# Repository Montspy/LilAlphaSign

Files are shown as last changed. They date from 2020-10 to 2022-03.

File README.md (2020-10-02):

# LilAlphaSign
Little experiment at a WiFi connected RGB sign.
Background and "alert" animations can be triggered through HTTP requests.
User Manual: [here](extras/LilAlphaSign%20User%20Manual.pdf)

### Web interface

Web interface video (http://www.youtube.com/watch?v=FNkgUU_1f1U "Click to watch")

### Background animations

Web interface video (http://www.youtube.com/watch?v=0p3MXtC2Jag "Click to watch")

### "Alert" animations

Web interface video (http://www.youtube.com/watch?v=xB9izgtYmIM "Click to watch")

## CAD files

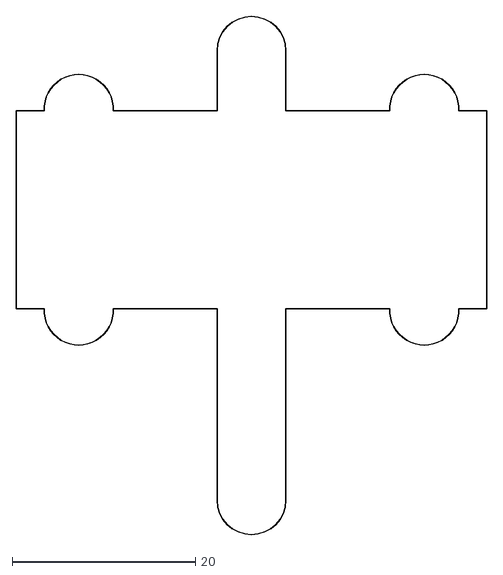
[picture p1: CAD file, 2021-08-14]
extras/cad/diffusers/dxf exports/SamW Sign - Jets acrylic diffuser.dxf
51.3 x 56.5

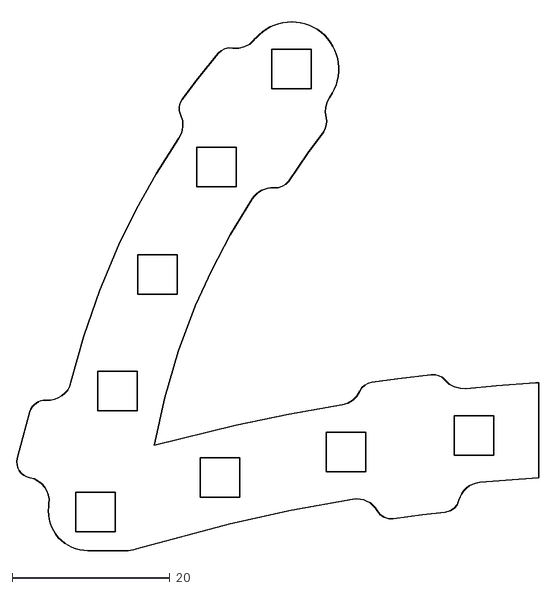
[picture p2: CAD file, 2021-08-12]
extras/cad/pcb outlines/PCB - SamW Sign - LED board 1.dxf
66.1 x 67.7

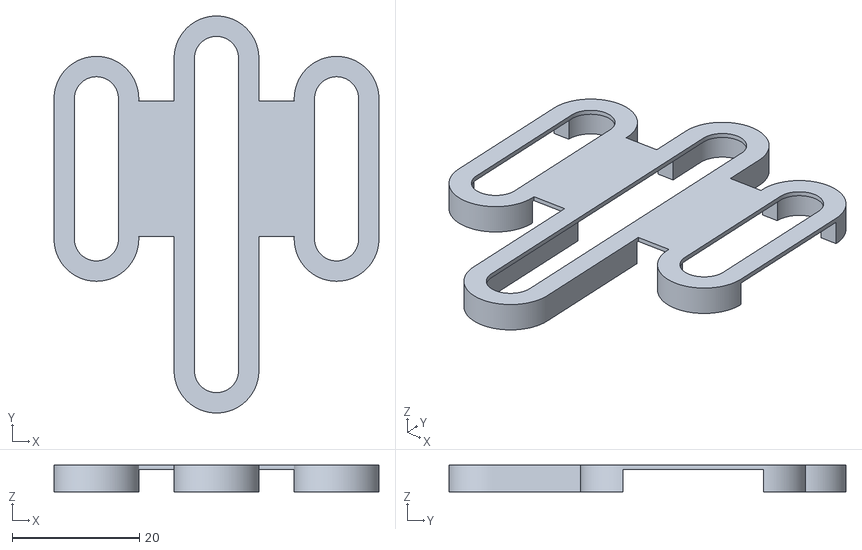
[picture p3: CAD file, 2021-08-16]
extras/cad/stl/Housing - SamW Sign - Jets cover.stl
51.0 x 62.3 x 4.17

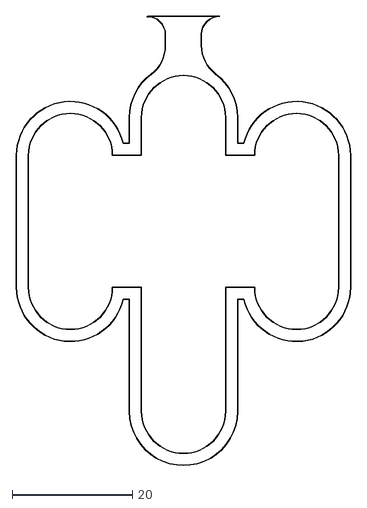
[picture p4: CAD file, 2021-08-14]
extras/cad/diffusers/dxf exports/SamW Sign - Jets.dxf
55.7 x 75.3

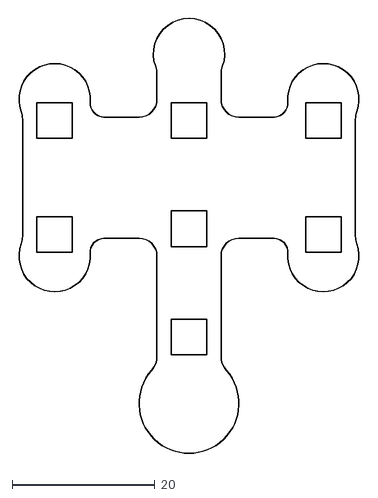
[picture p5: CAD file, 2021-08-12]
extras/cad/pcb outlines/PCB - SamW Sign - LED board jets.dxf
48.5 x 62.0

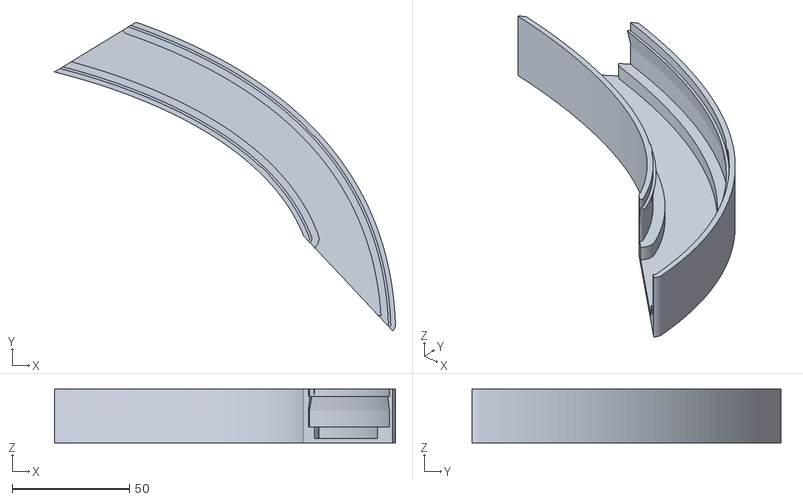
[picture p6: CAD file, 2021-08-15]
extras/cad/stl/Housing - SamW Sign - Rocket mid.stl
145.2 x 131.5 x 23.0

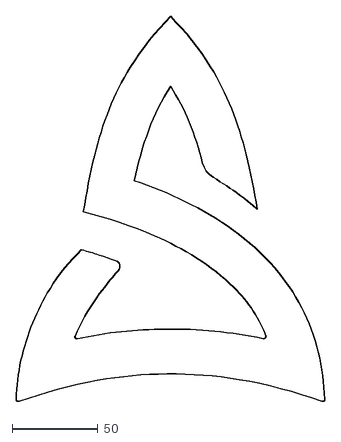
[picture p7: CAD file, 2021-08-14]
extras/cad/diffusers/dxf exports/SamW Sign - Rocket acrylic diffuser.dxf
179.7 x 224.3

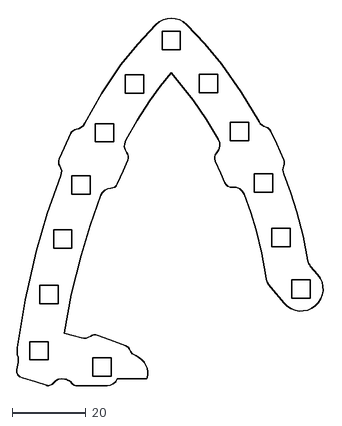
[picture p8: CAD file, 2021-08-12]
extras/cad/pcb outlines/PCB - SamW Sign - LED board 3.dxf
84.0 x 100.4

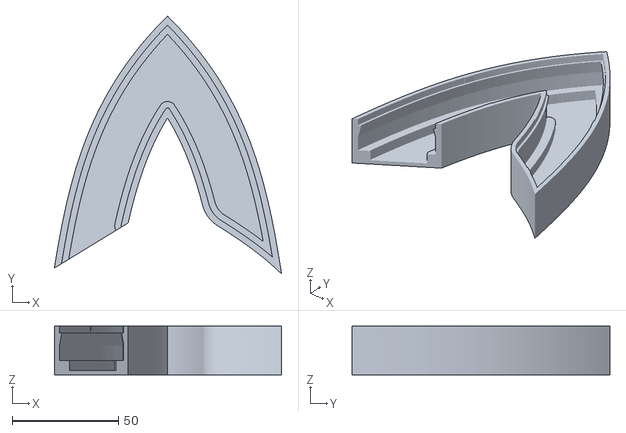
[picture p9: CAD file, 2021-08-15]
extras/cad/stl/Housing - SamW Sign - Rocket top.stl
106.9 x 121.3 x 23.0

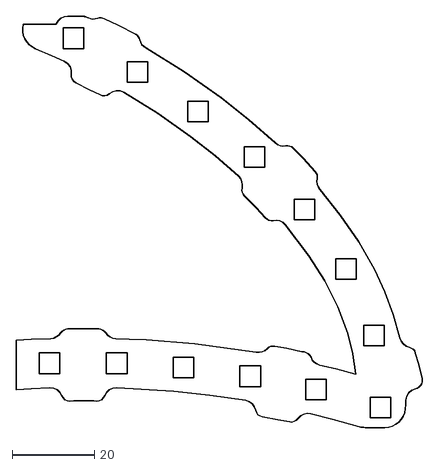
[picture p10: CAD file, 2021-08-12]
extras/cad/pcb outlines/PCB - SamW Sign - LED board 2.dxf
98.8 x 100.0

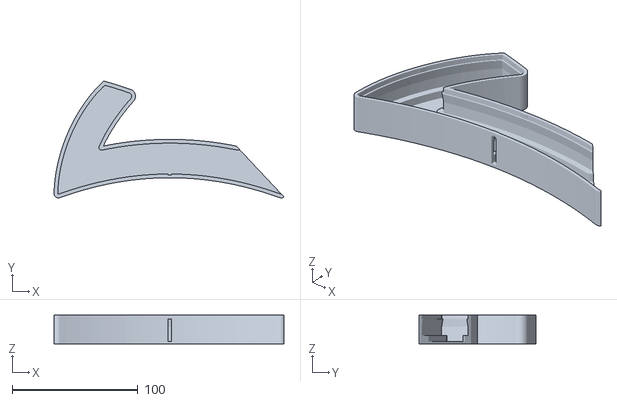
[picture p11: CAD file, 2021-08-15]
extras/cad/stl/Housing - SamW Sign - Rocket bottom.stl
182.9 x 93.0 x 23.0

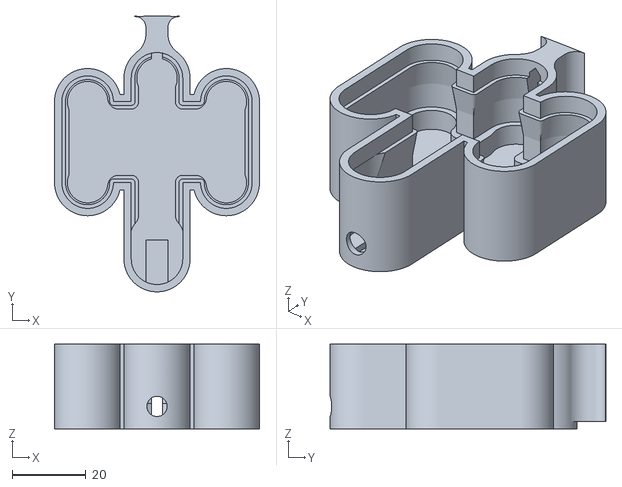
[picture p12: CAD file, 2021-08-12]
extras/cad/stl/Housing - SamW Sign - Jets.stl
55.7 x 74.9 x 23.0

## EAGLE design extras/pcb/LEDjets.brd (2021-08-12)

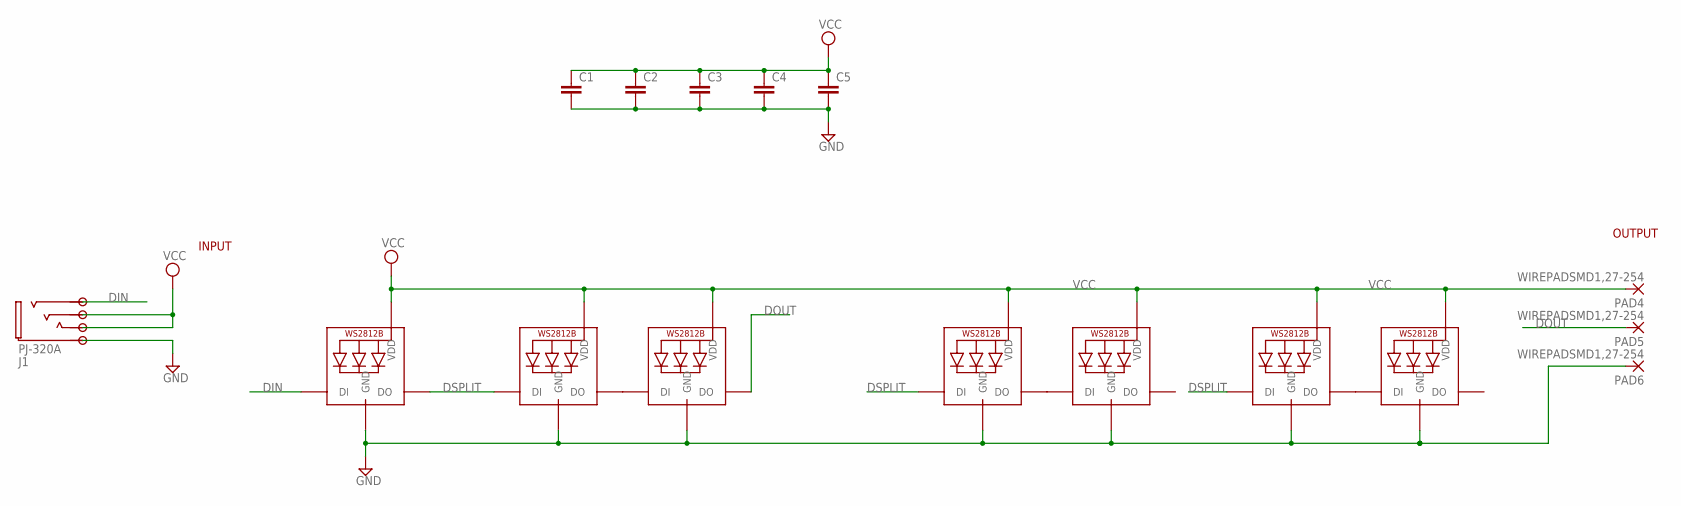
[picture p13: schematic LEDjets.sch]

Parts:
C1, C2, C3, C4, C5: C-EUC0805K; C0805K
J1: PJ-320A
LED1, LED2, LED3, LED4, LED5, LED6, LED7: WS2812B5050; WS2812B
PAD4, PAD5, PAD6: WIREPADSMD1,27-254; SMD1,27-2,54

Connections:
DIN: J1.2, LED1.4-DIN (DI)
DOUT: LED3.2-DOUT (DO), PAD5.1
DSPLIT: LED1.2-DOUT (DO), LED2.4-DIN (DI), LED4.4-DIN (DI), LED6.4-DIN (DI)
GND: C1.2, C2.2, C3.2, C4.2, C5.2, J1.5, LED1.3-GND (GND), LED2.3-GND (GND), LED3.3-GND (GND), LED4.3-GND (GND), LED5.3-GND (GND), LED6.3-GND (GND), LED7.3-GND (GND), PAD6.1
unnamed: LED2.2-DOUT (DO), LED3.4-DIN (DI)
unnamed: LED4.2-DOUT (DO), LED5.4-DIN (DI)
unnamed: LED6.2-DOUT (DO), LED7.4-DIN (DI)
VCC: C1.1, C2.1, C3.1, C4.1, C5.1, J1.3, J1.4, LED1.1-VDD (VDD), LED2.1-VDD (VDD), LED3.1-VDD (VDD), LED4.1-VDD (VDD), LED5.1-VDD (VDD), LED6.1-VDD (VDD), LED7.1-VDD (VDD), PAD4.1

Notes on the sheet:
INPUT
OUTPUT

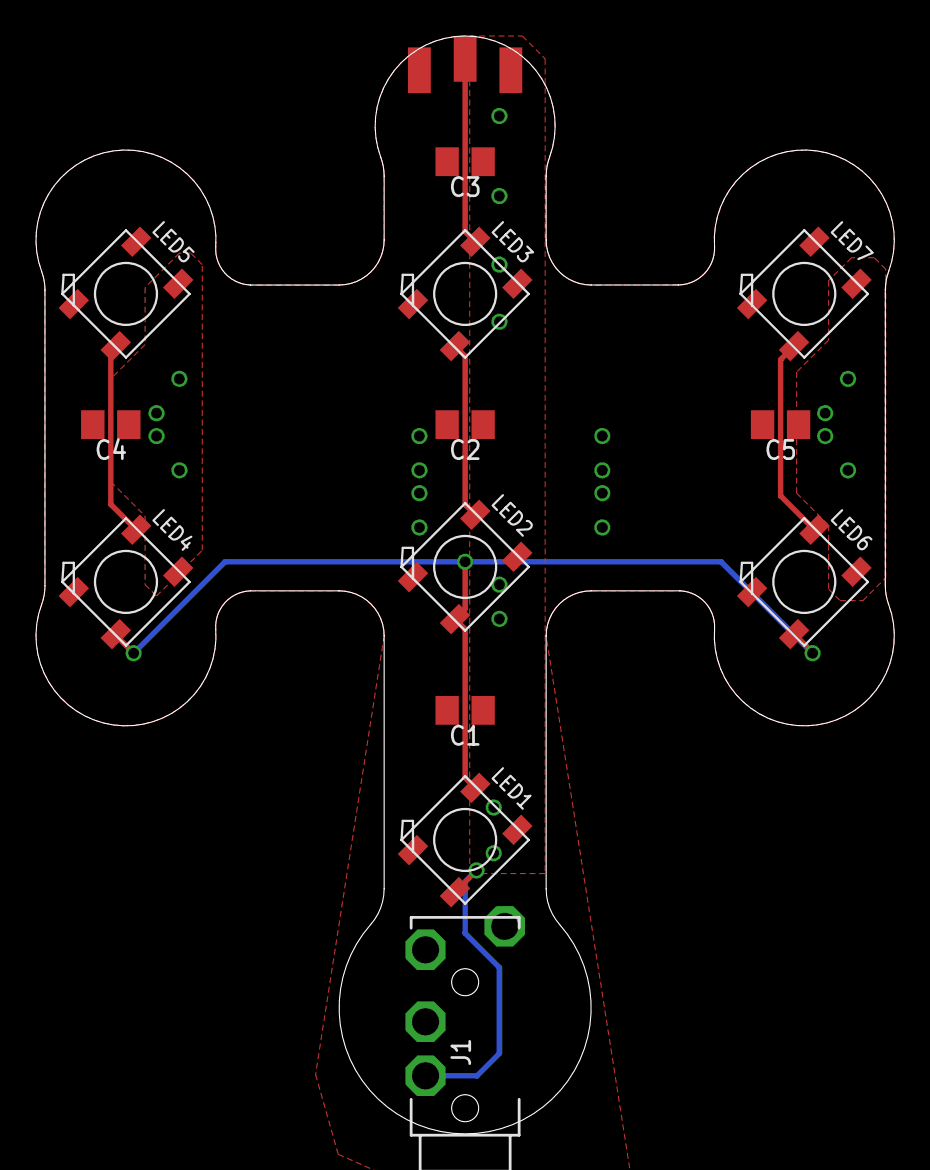
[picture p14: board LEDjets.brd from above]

Board: 2 copper layers, 47.7 x 61.0 mm, 16 parts (0 on the bottom side), 8 nets.

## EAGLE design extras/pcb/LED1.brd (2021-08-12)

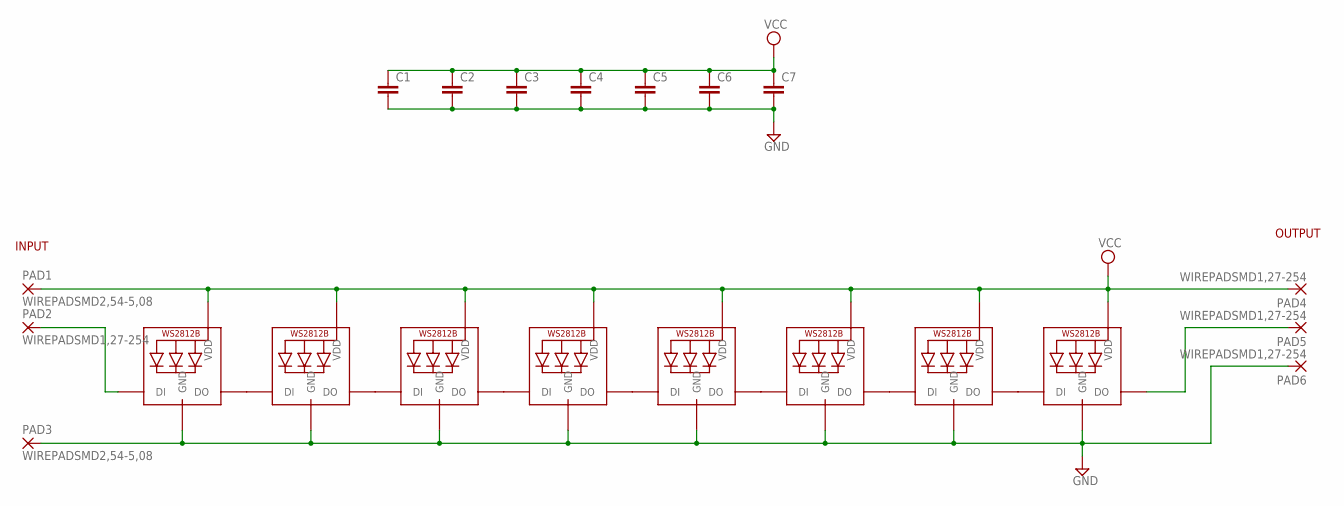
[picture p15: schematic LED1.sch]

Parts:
C1, C2, C3, C4, C5, C6, C7: C-EUC0805K; C0805K
LED1, LED2, LED3, LED4, LED5, LED6, LED7, LED8: WS2812B5050; WS2812B
PAD1, PAD3: WIREPADSMD2,54-5,08; SMD2,54-5,08
PAD2, PAD4, PAD5, PAD6: WIREPADSMD1,27-254; SMD1,27-2,54

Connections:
GND: C1.2, C2.2, C3.2, C4.2, C5.2, C6.2, C7.2, LED1.3-GND (GND), LED2.3-GND (GND), LED3.3-GND (GND), LED4.3-GND (GND), LED5.3-GND (GND), LED6.3-GND (GND), LED7.3-GND (GND), LED8.3-GND (GND), PAD3.1, PAD6.1
unnamed: LED1.2-DOUT (DO), LED2.4-DIN (DI)
unnamed: LED2.2-DOUT (DO), LED3.4-DIN (DI)
unnamed: LED3.2-DOUT (DO), LED4.4-DIN (DI)
unnamed: LED4.2-DOUT (DO), LED5.4-DIN (DI)
unnamed: LED5.2-DOUT (DO), LED6.4-DIN (DI)
unnamed: LED6.2-DOUT (DO), LED7.4-DIN (DI)
unnamed: LED1.4-DIN (DI), PAD2.1
unnamed: LED8.2-DOUT (DO), PAD5.1
unnamed: LED7.2-DOUT (DO), LED8.4-DIN (DI)
VCC: C1.1, C2.1, C3.1, C4.1, C5.1, C6.1, C7.1, LED1.1-VDD (VDD), LED2.1-VDD (VDD), LED3.1-VDD (VDD), LED4.1-VDD (VDD), LED5.1-VDD (VDD), LED6.1-VDD (VDD), LED7.1-VDD (VDD), LED8.1-VDD (VDD), PAD1.1, PAD4.1

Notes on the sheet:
INPUT
OUTPUT

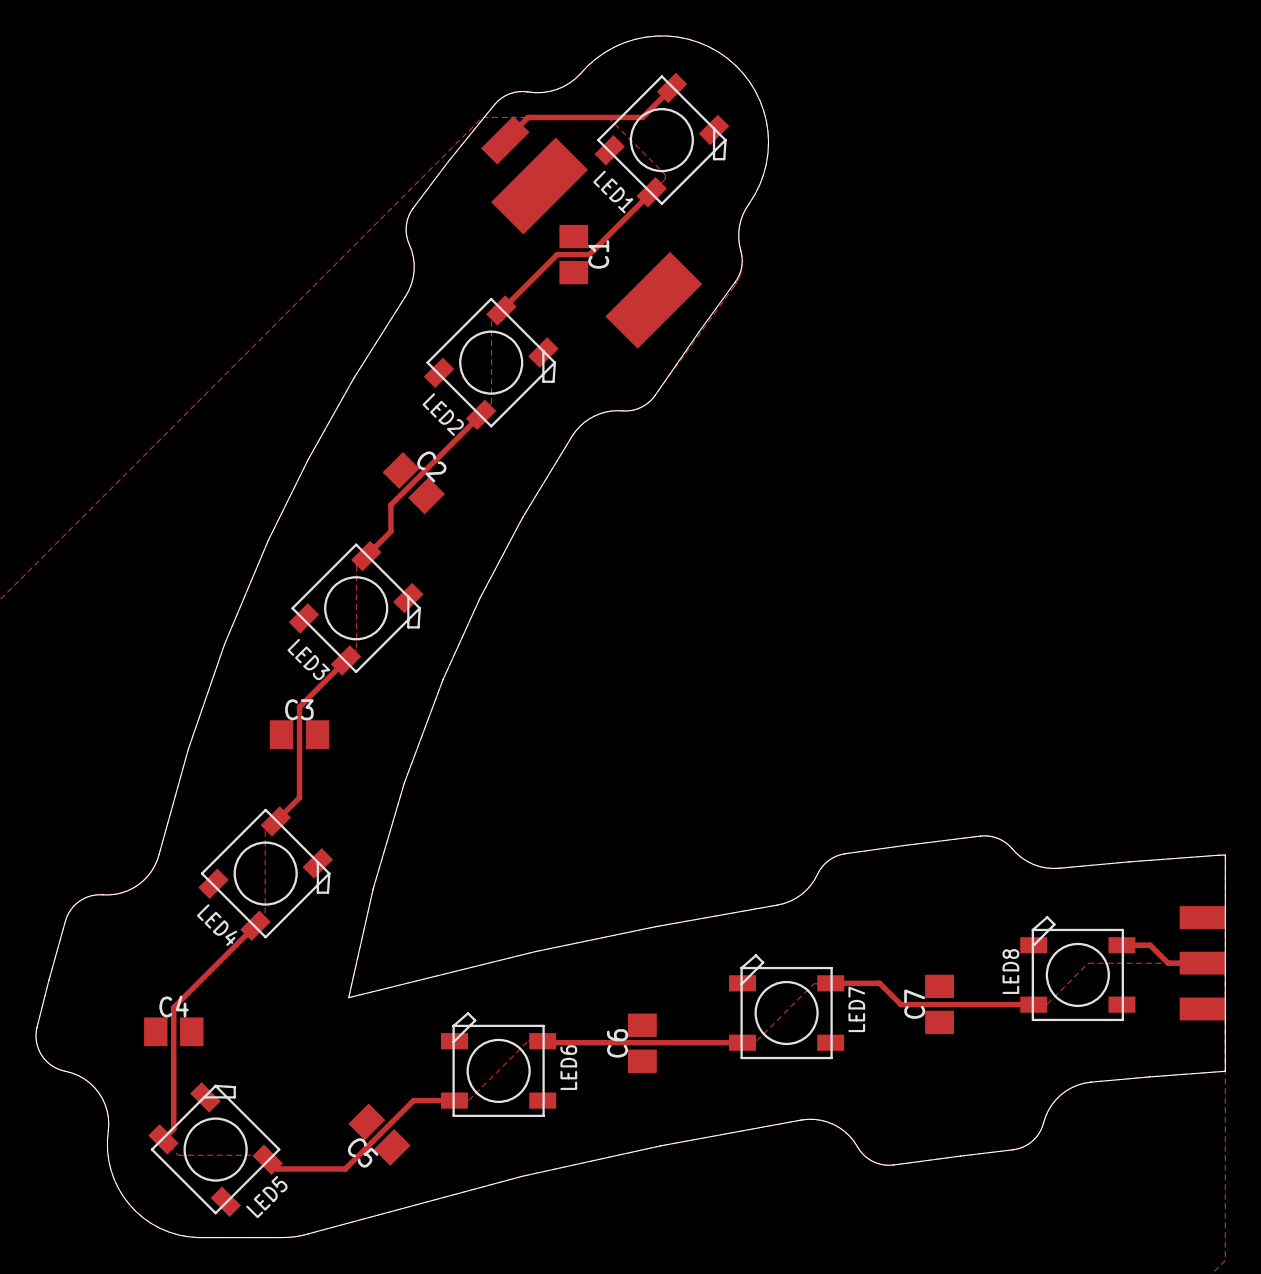
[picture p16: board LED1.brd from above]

Board: 2 copper layers, 66.1 x 66.8 mm, 21 parts (0 on the bottom side), 11 nets.

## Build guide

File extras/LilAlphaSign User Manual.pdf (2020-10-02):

# Lil AlphaSign

# User Manual

# Setting up Wifi

This setup only needs to be done once.

1. Plug the 12V adapter to the mains and to the controller box.
2. Open your phone WiFi settings and look for a new WiFi network named “Lil AlphaSign”.

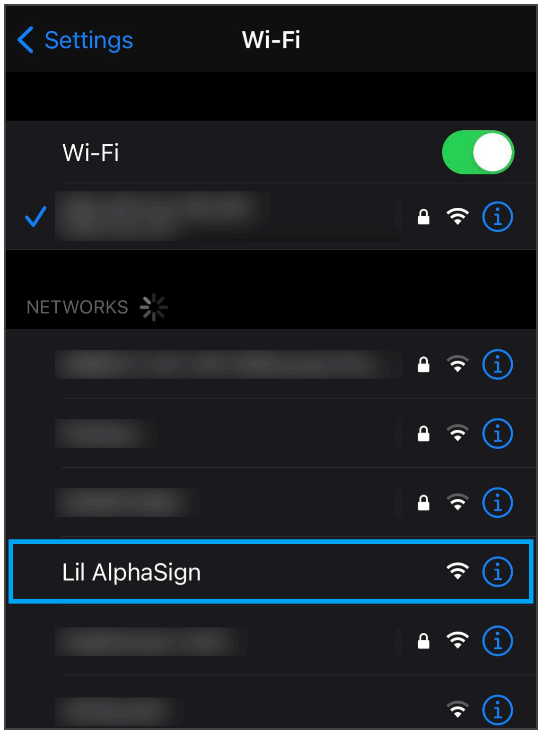
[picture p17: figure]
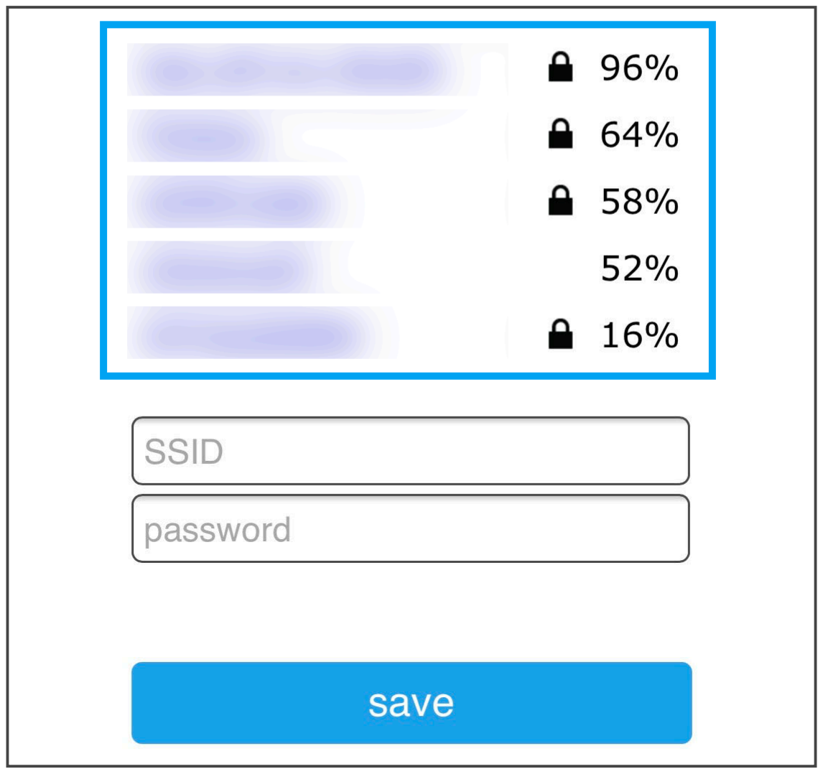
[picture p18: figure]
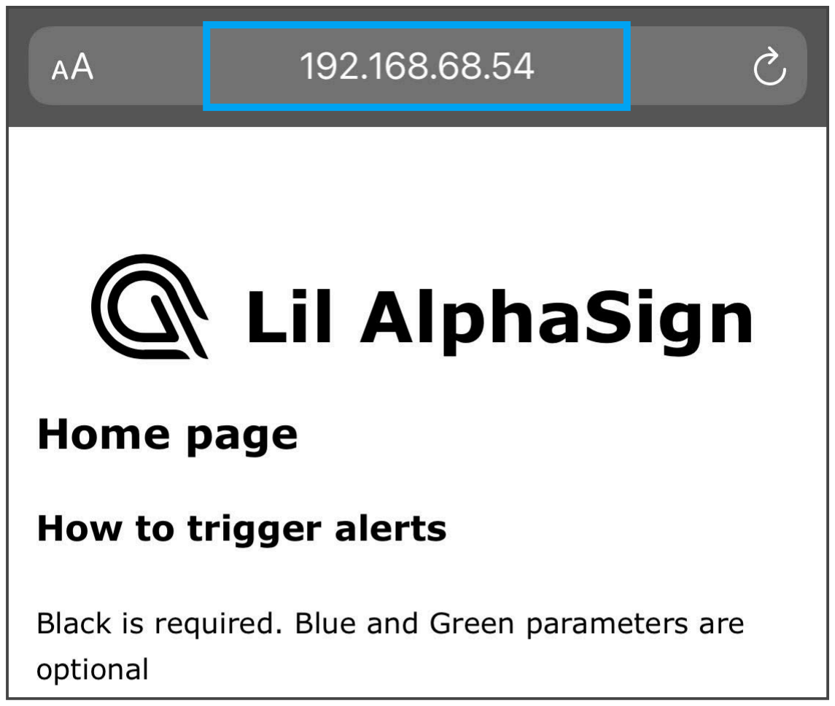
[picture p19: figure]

3. Connect to it.
4. A popup will appear. Hit “Configure WiFi”. If no portal appears, try navigating to google.com in your web browser.

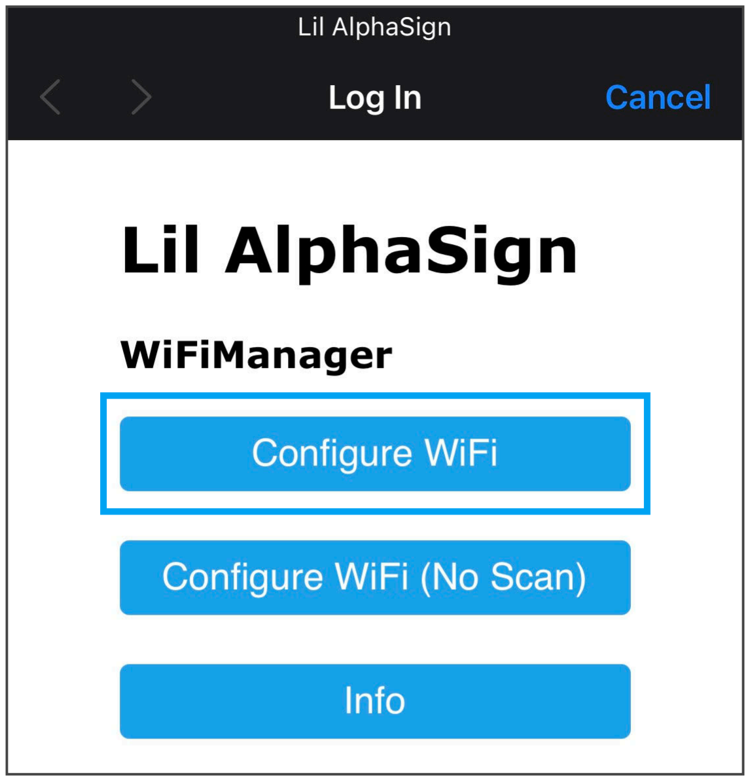
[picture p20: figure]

5. The controller will scan for local WiFi networks. Select yours in the list and fill in your WiFi password. Hit “save"
6. The controller will restart and attempt to connect to your WiFi network.
7. Once the LEDs come on, use your router interface to find the sign’s IP address (usually in “connected devices”).
It will show up as “ESP-4F18EA”.

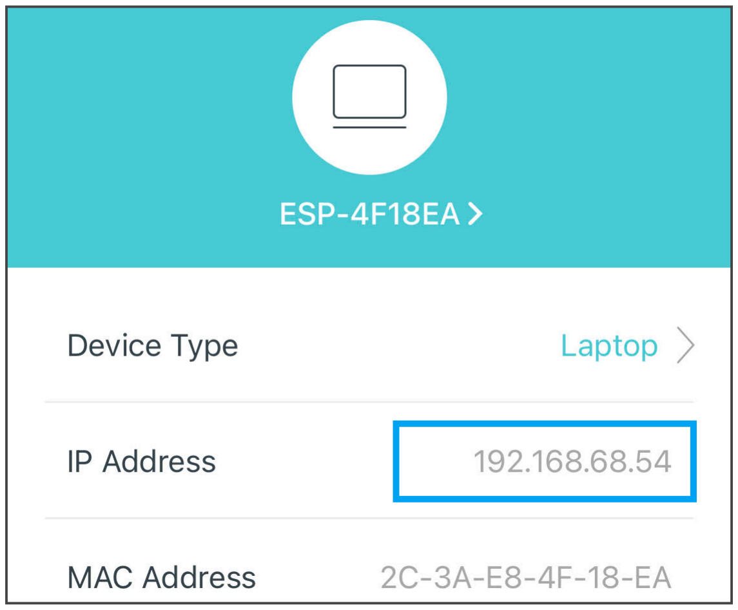
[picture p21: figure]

8. Your sign is correctly connected to your WiFi network. You can start using it.
9. Navigate to its IP address using any web browser on the same network.

Lil AlphaSign User Manual – Rev 1

# Using the sign

Once connected to WiFi, the sign will indefinitely display the default background animation.

When triggered, alert animations will fade in, execute, then fade back out to the background.

Backgrounds

A default background can be selected from 5 background animations:
1. Rainbow
2. Cycle hues
3. Off
4. Solid color
5. Heartbeat

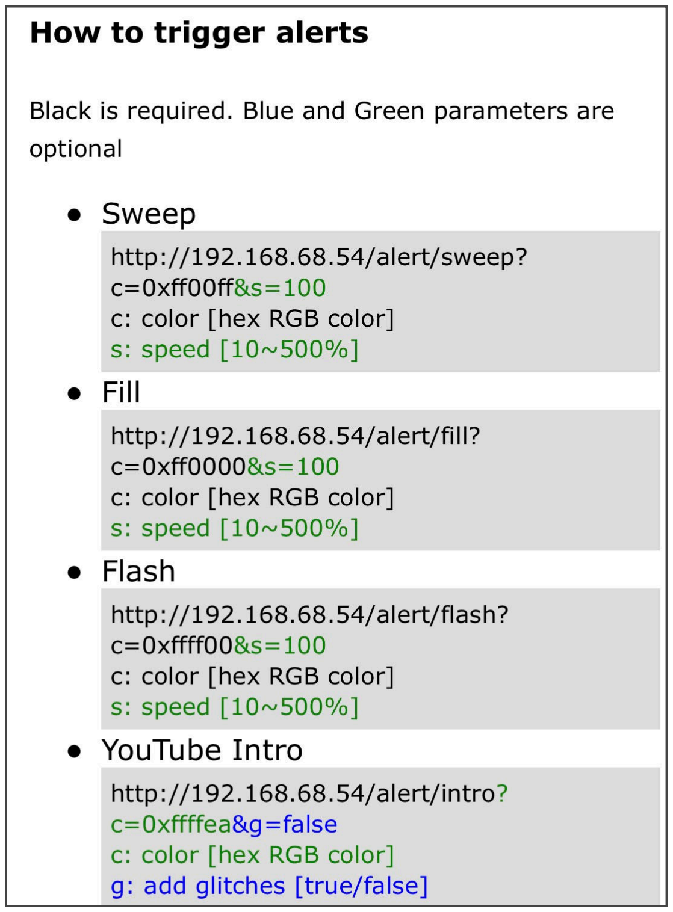
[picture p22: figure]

The selection can be done in the settings page (see settings section) or via HTTP requests as indicated on the homepage of the sign.

Alerts

They are short <5s animations that fade in / out. They can be triggered in the settings page or via HTTP requests for integration with your stream! 4 alert animations are provided and can be customized:
1. Sweep
2. Fill
3. Flash
4. “YouTube Intro”

Sweep, Fill and Flash alerts require a color parameter every time they are triggered.
This way, the same alert can be used for different events (followers, subs, …), each with a different color.

HTTP requests

This sign has been designed to be easily integrated with custom widgets, Stream Decks and such.
All of its functionalities can be triggered and customized via simple calls to a local URL hosted by the controller (thus the WiFi connection).

Whichever way you use to send the HTTP request, the URL and parameters are described on the homepage of the sign: “How to change the background” and “How to trigger alerts”

http://<deviceIP>/
Widgets integration

For custom StreamElements widgets, the easiest way to trigger an alert or a background change is to us the fetch function:

fetch(‘http://<deviceIP>/alert/intro’);
Or

fetch(‘http://<deviceIP>/bg/color?c=0xff0000’);
Stream Deck integration untested

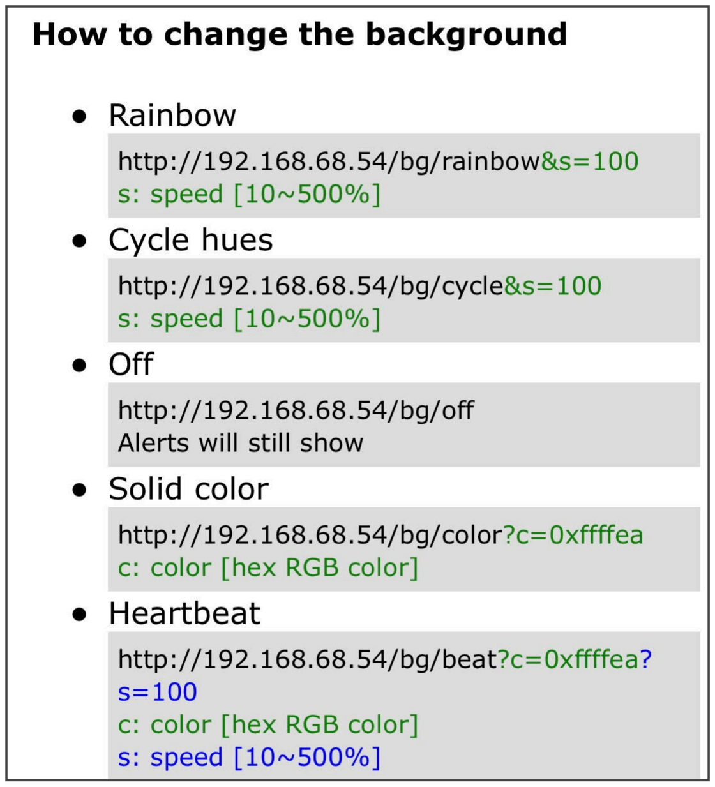
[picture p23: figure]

Stream Deck integration to the Stream Deck has not been tested.
1. “System Action - Website” should work out of the box but opens a web browser window every time.
2. Stream Deck plugins supporting HTTP requests or “webhooks”. I am looking for a reliable one, but would not be able to test without Stream Deck. Let me know if you want to set it up. I’ll help!

# Settings

The settings page can be accessed via any web browser at the address:

http://<deviceIP>/settings

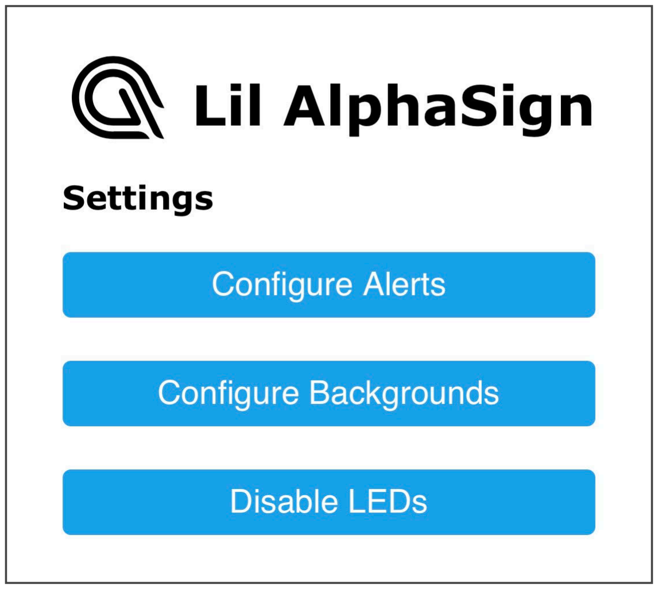
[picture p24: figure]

Configure Alerts

Each alert is listed with its specific setting(s) and a “Try it!” button.

Sweep, Fill and Flash alerts don’t have a color setting as they require that parameter each time they are triggered

Once you are happy with the settings, click the “Save” button to save the settings.

Configure Backgrounds

The default background (the one to be displayed) can be selected at the top.

You’ll then find the specific settings for each background as well as a “Try it!” button.

Once you are happy with the settings, click the “Save” button to save the settings.

Enable/Disable LEDs

This button allows you to turn the LEDs off until you re-enable them. Backgrounds and alerts will not be displayed.

If you want to see the alerts, but turn off the background, you can select the “Off” background as default in the “Configure Backgrounds” page.

# More help?

Need more help to setup or use it? More features?

Shoot me an email or find me on Twitter:

valentin.trimaille@gmail.com

@sQweegle

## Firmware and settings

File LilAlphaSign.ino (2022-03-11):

/***
 * Board: NodeMCU 32S (ESP-WROOM-32)
 * Libraries: see Application.h file
 * Additional: 
 *     + Upload files data/config.json to LittleFS after full flash erase (https://github.com/lorol/arduino-esp32fs-plugin#installation), you may need to upgrade to esptool v3.1 (https://github.com/espressif/esptool/releases/tag/v3.1)
 */

#include "Application.h"
#include "Animation.h"
#include "Background.h"
#include "Controller.h"

void configModeCallback (WiFiManager *myWiFiManager) {
  Serial.println("Entered config mode");
  Serial.println(WiFi.softAPIP());
  //if you used auto generated SSID, print it
  Serial.println(myWiFiManager->getConfigPortalSSID());
}

WebServer server;

FASTLED_USING_NAMESPACE
CRGB aLeds[NUM_LEDS];
CRGB bLeds[NUM_LEDS];
CRGB outLeds[NUM_LEDS];

Animation* currAnim = NULL;
Background* currBg = NULL;
bool isOn = true;

uint8_t gHue = 0;

Controller ctrl(&server, &currAnim, &currBg);

void setup() {
  // put your setup code here, to run once:
  Serial.begin(115200);

  if (!LITTLEFS.begin()) {
    Serial.println("Failed to mount file system");
    return;
  }
  ctrl.loadConfig();
  
  //WiFiManager
  //Local intialization. Once its business is done, there is no need to keep it around
  WiFiManager wifiManager;

  //set callback that gets called when connecting to previous WiFi fails, and enters Access Point mode
  wifiManager.setAPCallback(configModeCallback);
  wifiManager.setHostname(HOST_NAME);

  //fetches ssid and pass and tries to connect
  //if it does not connect it starts an access point with the specified name
  //and goes into a blocking loop awaiting configuration
  if(!wifiManager.autoConnect(AP_NAME)) {
    Serial.println("failed to connect and hit timeout");
    //reset and try again, or maybe put it to deep sleep
    ESP.restart();
    delay(1000);
  } 

  // if you get here you have connected to the WiFi
  Serial.println("connected...yeey :)");
  
  Serial.print("Local IP: ");
  Serial.println(WiFi.localIP());
  
  if(MDNS.begin("samw-sign"))
    Serial.println("MDNS Responder Started!");

  // tell FastLED about the LED strip configuration
  FastLED.addLeds<LED_TYPE,DATA_PIN,COLOR_ORDER>(outLeds, NUM_LEDS).setCorrection(TypicalLEDStrip);
  //FastLED.addLeds<LED_TYPE,DATA_PIN,CLK_PIN,COLOR_ORDER>(leds, NUM_LEDS).setCorrection(TypicalLEDStrip);

  // set master brightness control
  FastLED.setBrightness(STRIP_BRIGHTNESS);

  // start serving HTTP requests
  server.begin();

  // clear led buffer arrays
  fill_solid(aLeds, NUM_LEDS, 0x000000);
  fill_solid(bLeds, NUM_LEDS, 0x000000);
  fill_solid(outLeds, NUM_LEDS, 0x000000);
  
  ctrl.initBg();
}

void loop() {
  handleWifiTasks();

  // send the 'leds' array out to the actual LED strip
  EVERY_N_MILLISECONDS(1000/FRAMES_PER_SECOND) {
    if(!ctrl.getLedsOn()) {
      fill_solid(outLeds, NUM_LEDS, 0x000000);
    }
    else {
      // Background!
      if(currBg != NULL) { 
        currBg->execute(bLeds);
      }
      
      // Animate alerts away!
      fract8 animOpacity = 0;
      if(currAnim != NULL) {
        if(currAnim->execute(aLeds)) {
          animOpacity = currAnim->getAlpha();
        }
        else {  // Delete animation once it's completed
          delete currAnim;
          currAnim = NULL;
        }
      }

      // Merge bg and anim
      blend(bLeds, aLeds, outLeds, NUM_LEDS, animOpacity);
    }
    
    FastLED.show();
  }
}

void handleWifiTasks() {
  if(ensureWifi()) {
    server.handleClient();
  }
  else {
  }
}

bool ensureWifi() {
  if (WiFi.status() != WL_CONNECTED) {
    Serial.println("Disconnected :(");
    WiFiManager wifiManager;
    wifiManager.setConnectTimeout(180);
    wifiManager.setTimeout(180);
    
    wifiManager.autoConnect(AP_NAME);
  }
  
  return (WiFi.status() == WL_CONNECTED);
}

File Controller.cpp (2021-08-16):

#include "Controller.h"

Controller::Controller(WebServer* server,  Animation** pCurrAnim, Background** pCurrBg) : server(server), pCurrAnim(pCurrAnim), pCurrBg(pCurrBg) {
  this->setupHandlers();
}

// LEDs
bool Controller::getLedsOn() {
  return this->ledsOn;
}

void Controller::setLedsOn(bool on) {
  this->ledsOn = on;
}

void Controller::initBg() {
  Background* bg = NULL;
  String bg_default = String(this->getBgDefault());
  
  if(bg_default == "rainbow") {
    bg = new RainbowBackground(scale16by8(this->getBgRainbowSpeed(), 38), false);  // Convert from 100% speed to 15bpm (38/256 ~ 15/100)
  }
  else if(bg_default == "cycle") {
    bg = new CycleBackground(scale16by8(this->getBgCycleSpeed(), 38));  // Convert from 100% speed to 15bpm (38/256 ~ 15/100)
  }
  else if(bg_default == "off") {
    bg = new OffBackground();
  }
  else if(bg_default == "color") {
    bg = new ColorBackground(CRGB(this->getBgColorColor()));
  }
  else if(bg_default == "beat") {
    bg = new BeatBackground(CRGB(this->getBgBeatColor()), scale16by8(this->getBgBeatSpeed(), 38));  // Convert from 100% speed to 15bpm (38/256 ~ 15/100)
  }
  
  this->startBackground(bg);
}

void Controller::startAnimation(Animation* newAnim) {
  if(*(this->pCurrAnim) != NULL) {  // Interrupt currently running animation
    delete *(this->pCurrAnim);
    *(this->pCurrAnim) = NULL;
  }
  
  *(this->pCurrAnim) = newAnim;
}

void Controller::startBackground(Background* newBg) {
  if(*(this->pCurrBg) != NULL) {  // Interrupt currently running background
    delete *(this->pCurrBg);
    *(this->pCurrBg) = NULL;
  }
  
  *(this->pCurrBg) = newBg;
}

// Wifi
void Controller::setupHandlers() {
  this->server->on("/",               [this](){ this->handleRoot(); });
  this->server->on("/alert/sweep",    [this](){ this->handleAlert("sweep"); });
  this->server->on("/alert/fill",     [this](){ this->handleAlert("fill"); });
  this->server->on("/alert/flash",    [this](){ this->handleAlert("flash"); });
  this->server->on("/alert/intro",    [this](){ this->handleAlert("intro"); });
  this->server->on("/bg/rainbow",     [this](){ this->handleBg("rainbow"); });
  this->server->on("/bg/cycle",       [this](){ this->handleBg("cycle"); });
  this->server->on("/bg/off",         [this](){ this->handleBg("off"); });
  this->server->on("/bg/color",       [this](){ this->handleBg("color"); });
  this->server->on("/bg/beat",        [this](){ this->handleBg("beat"); });
  
  this->server->on("/settings",       [this](){ this->handleSettings(); });
  this->server->on("/settings/alert", HTTP_GET,  [this](){ this->handleSettingsAlert(); });
  this->server->on("/settings/alert", HTTP_POST, [this](){ this->saveSettingsAlert(); });
  this->server->on("/settings/bg",    HTTP_GET,  [this](){ this->handleSettingsBg(); });
  this->server->on("/settings/bg",    HTTP_POST, [this](){ this->saveSettingsBg(); });
  this->server->on("/off",            [this](){ this->handleOff(); });
  this->server->on("/on",             [this](){ this->handleOn(); });
}

void Controller::handleRoot() {
  Serial.println("handleRoot()");
  
  // Headers
  String page = FPSTR(HTTP_AGS_HEAD);
  page.replace("{v}", "Settings");
  page += FPSTR(HTTP_AGS_SCRIPT);
  page += FPSTR(HTTP_AGS_STYLE);
  page += FPSTR(HTTP_AGS_HEAD_END);

  // Content
  page += FPSTR(HTTP_AGS_TITLE);
  page.replace("{t}", AP_NAME);
  page += String(F("<h3>Home page</h3>"));
  String item = FPSTR(HTTP_AGS_HOME);
  item.replace("{ip}", WiFi.localIP().toString());
  page += item;

  // Footer
  String stickyFooter = FPSTR(HTTP_AGS_FOOTER);
  stickyFooter.replace("{v}", VERSION);
  page += stickyFooter;
  page += FPSTR(HTTP_AGS_END);

  this->server->sendHeader("Content-Length", String(page.length()));
  this->server->send(200, "text/html", page);
}

void Controller::handleAlert(String name) {
  Serial.println("handleAlert() " + name);
  
  if(name == "") {
    this->server->send(204);
    return;
  }
  else if((name == "sweep") || (name == "fill") || (name == "flash"))  {
    // Default parameters
    uint32_t speed = 100;
    CRGB color(0xFF0000);

    if(name == "sweep") {
      speed = this->getAlertSweepSpeed();
    }
    else if(name == "fill") {
      speed = this->getAlertFillSpeed();
    }
    else if(name == "flash") {
      speed = this->getAlertFlashSpeed();
    }

    // Requested parameters (if they exist)
    if(this->server->arg("c") != "") {
      uint32_t colorCode = parseColorCode(this->server->arg("c"));
      if(colorCode <= 0xFFFFFF) {
        color = CRGB(colorCode);
      }
    }
    if(this->server->arg("s") != "") {
      uint32_t number = parseNumber(this->server->arg("s"));
      if((number >= 10) && (number <= 500)) {
        speed = number;
      }
    }

    // Run the animation
    if(name == "sweep") {
      uint32_t total_ms = (uint32_t)6500 * 100 / speed;
      this->startAnimation(new SweepAnimation(total_ms, color));
    }
    else if(name == "fill") {
      uint32_t total_ms = (uint32_t)3250 * 100 / speed;
      this->startAnimation(new FillAnimation(total_ms, color));
    }
    else if(name == "flash") {
      uint32_t total_ms = (uint32_t)3250 * 100 / speed;
      this->startAnimation(new FlashAnimation(total_ms, color));
    }
  }
  else if(name == "intro") {
    // Default parameters
    CRGB color(this->getAlertIntroColor());
    bool glitchy = this->getAlertIntroGlitchy();
    
    // Requested parameters (if they exist)
    if(this->server->arg("c") != "") {
      uint32_t colorCode = parseColorCode(this->server->arg("c"));
      if(colorCode <= 0xFFFFFF) {
        color = CRGB(colorCode);
      }
    }
    if(this->server->arg("g") == "true") {
      glitchy = true;
    }
    
    // Run the animation
    this->startAnimation(new IntroAnimation(glitchy, color));
  }

  this->server->send(204);
}
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

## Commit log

2020-09-30 Moved cad to cad folder
    [Logo - Holder - curved.stl, Logo - Holder - straight.stl, Logo - Inner alpha.stl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]
2020-09-30 Updated cad for holders
    [Logo - Holder - cone.stl, Logo - Holder - curved.stl, Logo - Holder - straight.stl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]
2021-08-12 Rename AlphaGamingSign.ino to LilAlphaSign.ino
    For Arduino IDE consistency
2021-08-12 Added PCB files and CAD files for SamW sign
    [Housing - SamW Sign - Jets cover.stl, Housing - SamW Sign - Jets.stl, Housing - SamW Sign - Rocket bottom.stl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]
2021-08-12 Added PCB dru and cam files
2021-08-14 Moved cad files and added diffusers dxf/svg files
    [Housing - SamW Sign - Jets cover.stl, Housing - SamW Sign - Jets.stl, Housing - SamW Sign - Rocket bottom.stl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]
2021-08-15 Added 'grabby' fingers to help hold the front acrylic diffuser
    [Housing - SamW Sign - Rocket bottom.stl, Housing - SamW Sign - Rocket mid.stl, Housing - SamW Sign - Rocket top.stl]
2021-08-16 Refactoring to use ESP32 board to resolve flickering issues when serving HTTP requests
    [Controller.cpp, LilAlphaSign.ino]
2021-08-16 Fixed intro animation bug
    [Animation.cpp]
2021-08-16 Improved fit of Jets cover
    [Housing - SamW Sign - Jets cover.stl]
